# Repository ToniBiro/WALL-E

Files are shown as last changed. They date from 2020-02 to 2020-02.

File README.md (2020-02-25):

# WALL-E

We replicated the original Pixar friendly robot WALL-E.
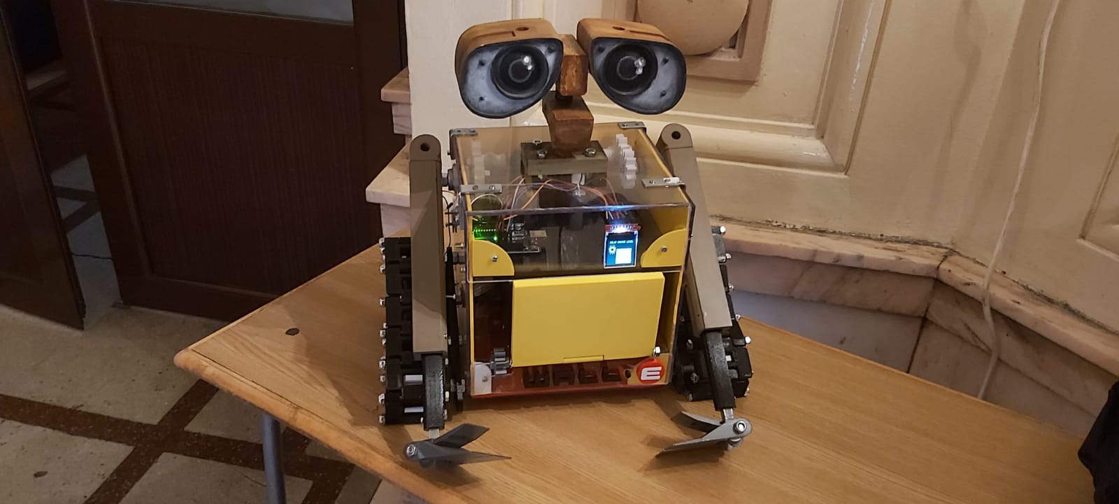
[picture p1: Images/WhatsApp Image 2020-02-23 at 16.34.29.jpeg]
our-wall-e


Wall-e is a robot that was left on earth to clean it up after the whole human race went off in space to live there while the earth was being cleaned up. He can move around, he can collect and compress the garbage and then pile it up in mountains (or solid and tidy structures).

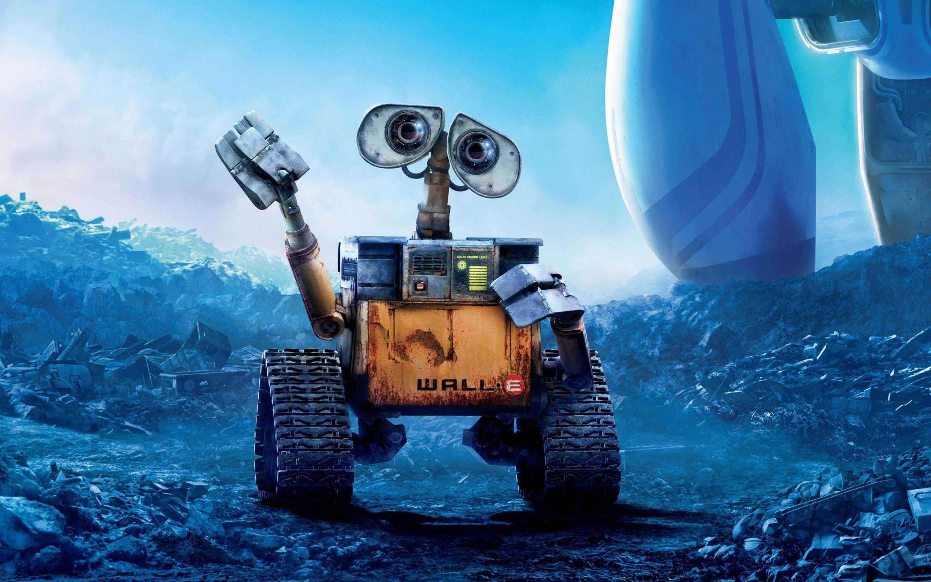
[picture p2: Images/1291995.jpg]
wall-e-original


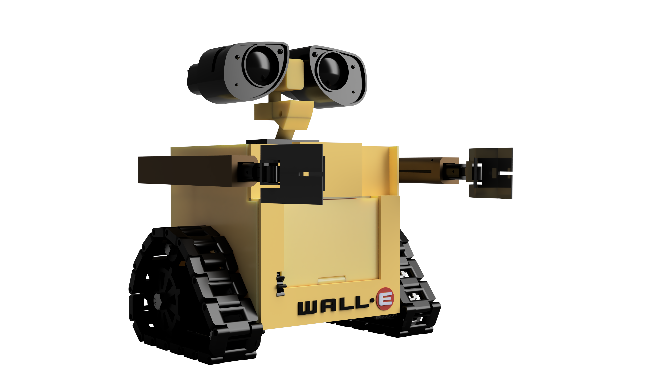
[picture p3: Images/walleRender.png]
  

### TEAM  
* [Antonia Biro-Balan](https://github.com/ToniBiro)
* [Mihai Stoian](https://github.com/mihainsto)

### Table of Contents
* [Features](#Features)
* [Usage](#Usage)
* [Video](#Video)
* [Roadmap](#Roadmap)
* [Materials and 3D models](#Materials)  

### Features
#### Overview
- Track/Wheel movement. He can move front and back but can't turn around yet.
- Arm movement. He can move them up and down but not front and back yet.
- Compression Room is existent but not completely assembeled yet.
- He is controlled via Bluetooth

#### Done
* Tracks movement  
the robot can move and rotate    
* Arm rotation  
the robot can move it's arms 180 deg  

#### To Do
* Hand slider movement  
* Compression chamber door movement  
* Assemble the compression process  

### Usage
The robot is controlled via a Bluetooth phone application.
While building him we used **Bluetooth RC Control** Android Mobile App.
We mapped all commands using this app but any other app can be used if we remap the command codes.

### Presentation Video  
[YouTube](https://youtu.be/xrvIICd3dlk)

## Roadmap
<table style="width:100%">

  <tr>
    <td>19 January</td>
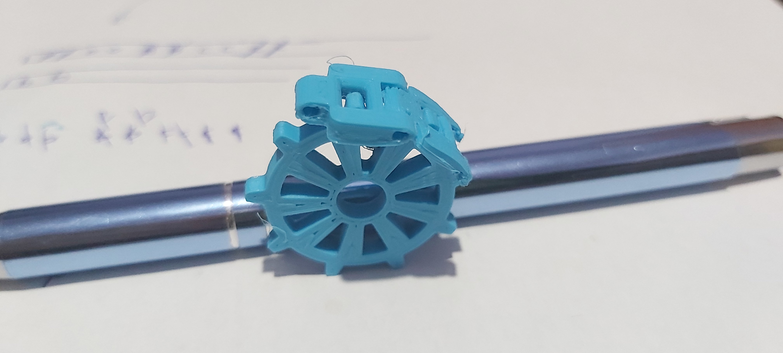
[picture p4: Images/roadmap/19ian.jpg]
    <td>
</td>
  </tr>
  <tr>
    <td>31 January</td>
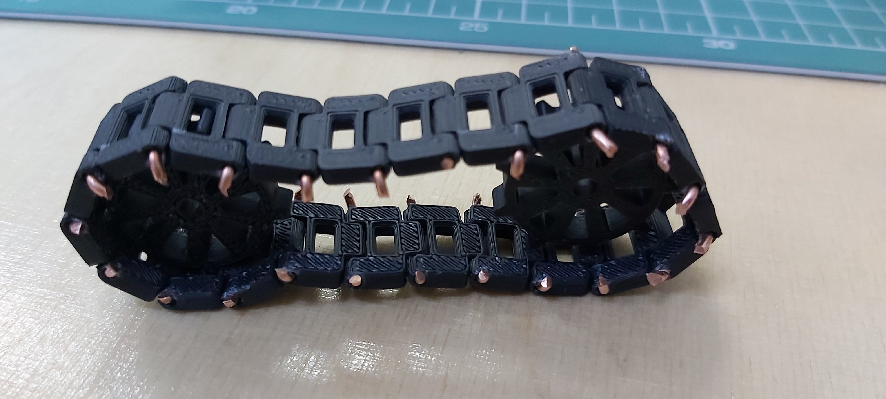
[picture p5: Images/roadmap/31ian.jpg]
    <td>
</td>
  </tr>
  <tr>
    <td>3 February</td>
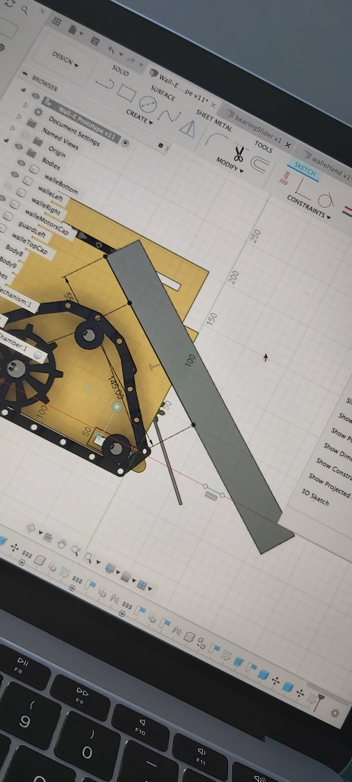
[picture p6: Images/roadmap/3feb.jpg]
    <td>
</td>
  </tr>
  <tr>
    <td>6 February</td>
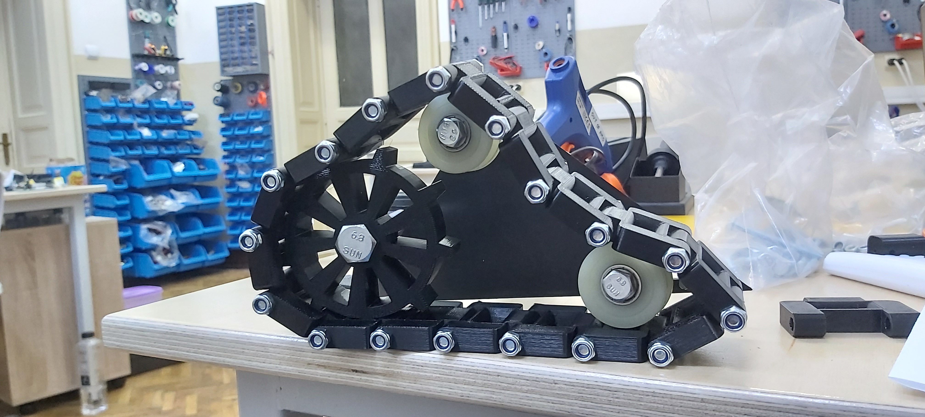
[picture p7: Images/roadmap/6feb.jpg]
    <td>
</td>
  </tr>
    <tr>
    <td>6 February</td>
    <td>
</td>
  </tr>
  <tr>
    <td>9 February</td>
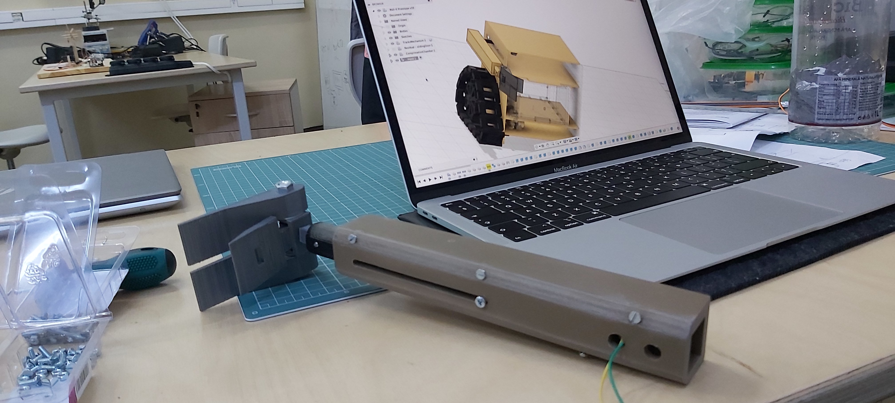
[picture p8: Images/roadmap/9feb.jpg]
    <td>
</td>
  </tr>
  <tr>
    <td>9 February</td>
    <td>
</td>
  </tr>
  <tr>
    <td>11 February</td>
    <td>
</td>
  </tr>
  <tr>
    <td>11 February</td>
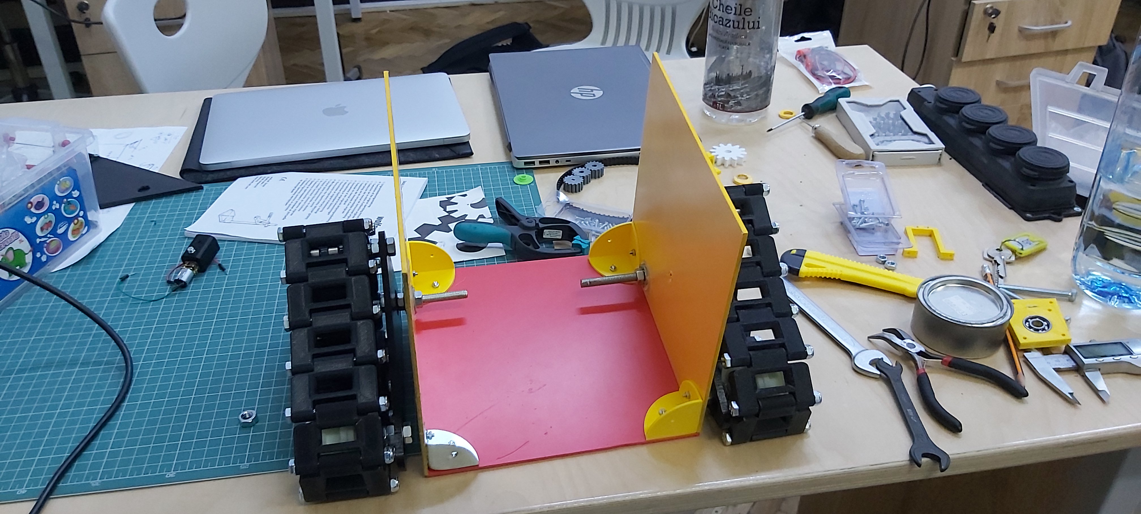
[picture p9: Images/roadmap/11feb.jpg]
    <td>
</td>
  </tr>
    <tr>
    <td>12 February</td>
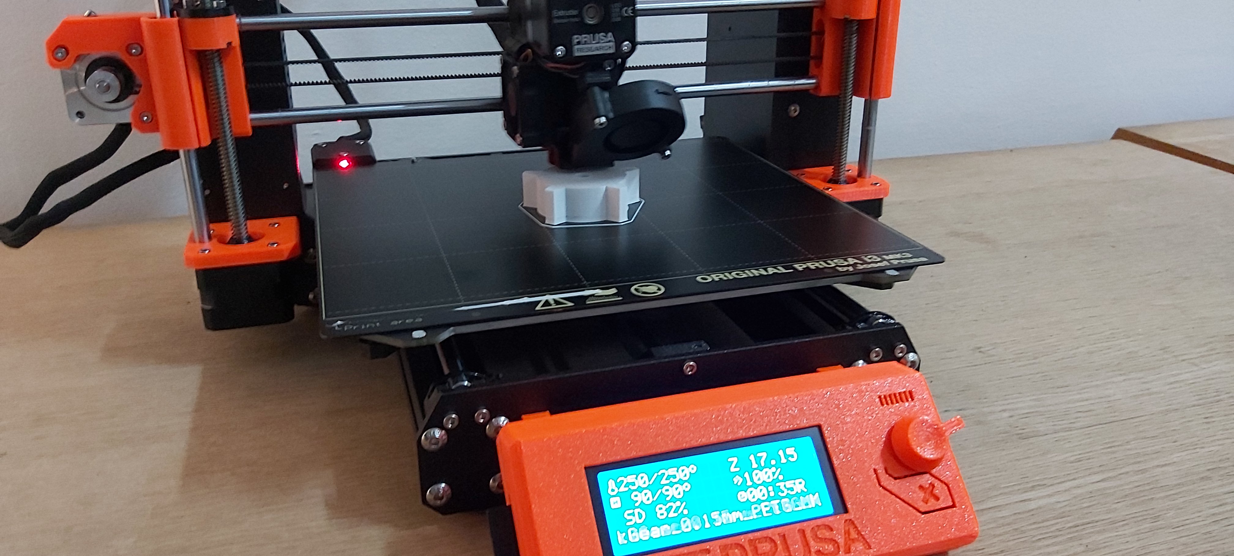
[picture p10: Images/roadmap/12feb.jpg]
    <td>
</td>
  </tr>
<tr>
    <td>15 February</td>
    <td>
</td>
  </tr>
  <tr>
    <td>20 February</td>
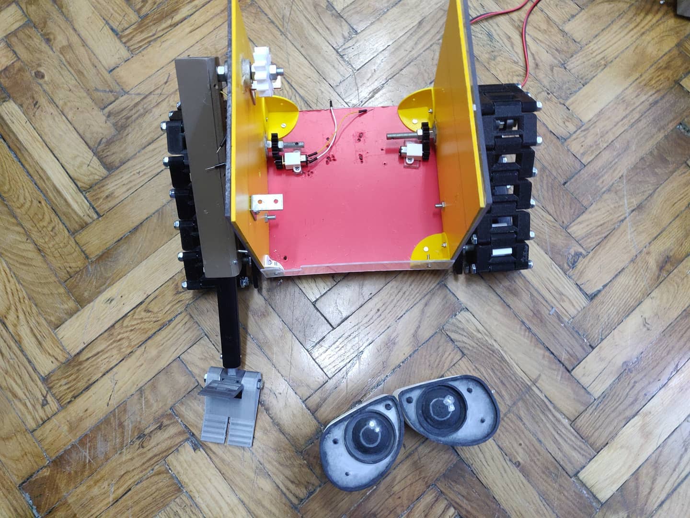
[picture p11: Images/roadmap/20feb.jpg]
    <td>
</td>
  </tr>
  </tr>
  <tr>
    <td>21 February</td>
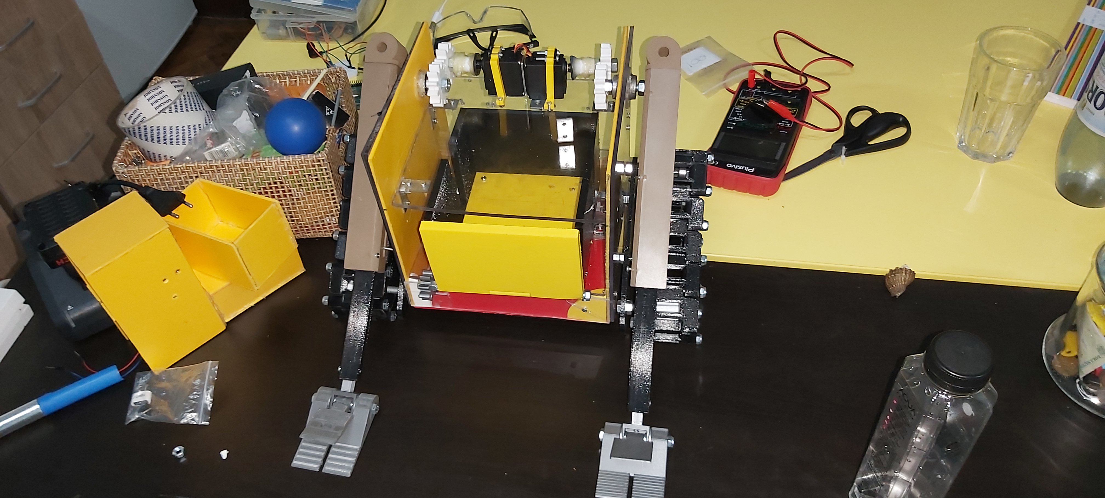
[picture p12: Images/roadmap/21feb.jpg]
    <td>
</td>
  </tr>
<tr>
    <td>22 February</td>
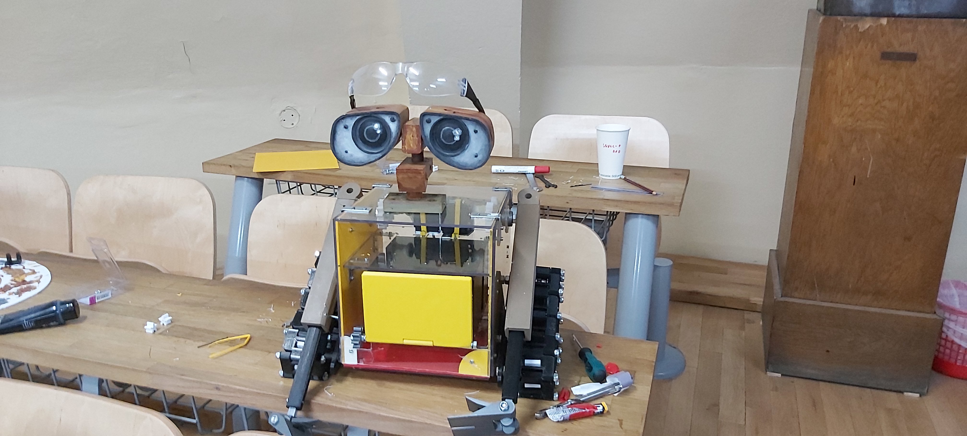
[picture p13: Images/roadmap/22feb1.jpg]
    <td>
</td>
  </tr>
  <tr>
    <td>22 February</td>
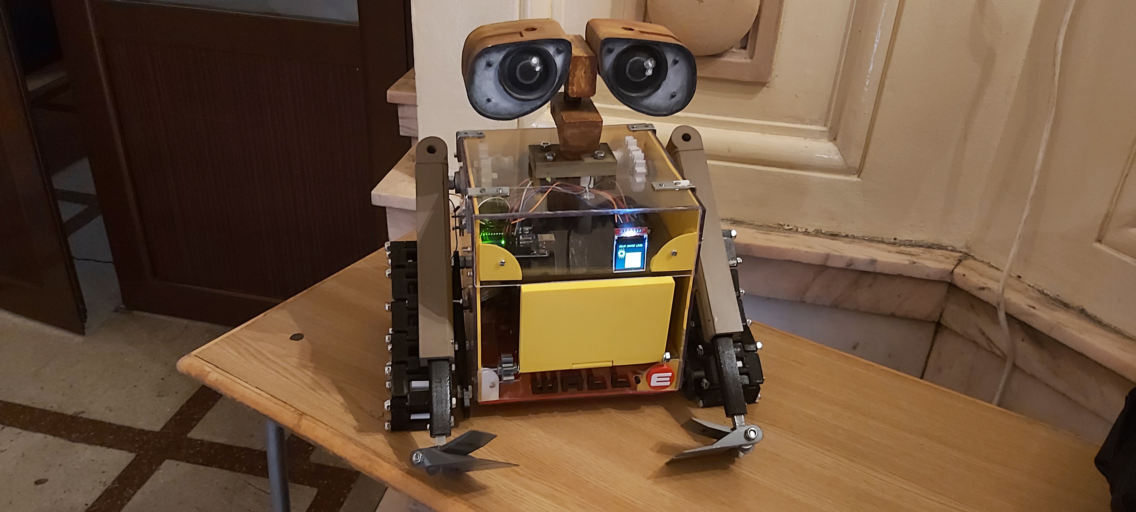
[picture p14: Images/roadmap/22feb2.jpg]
    <td>
</td>
  </tr>

</table>

### Materials and 3D models

#### Tracks
3D Printed - [files](/3D%20Parts/Tracks)
* 2x TractionGear
* 32x trackPiece
* 2x reinforcementTrackGuard
* 2x Gearbox Spur Gear (5 teeth)
* 2x Gearbox Spur Gear (10 teeth)
* 2x SmallTrackGear  

Other
* 2x 1000:1 DC Motors
* 8x 22 diameter bearings
* M8 M6 screws and nuts

#### Arm 
3D Printed - [files](/3D%20Parts/Arm)
* LeftArmleft
* LeftArmright
* LeftArmCoup
* LeftArmCilinder
* RightArmLeft
* RightArmright
* RightArmCoup
* RightArmCilinder
* 2x MotorCoupling
* 4x SpurGearArm
* 2x servoVerticalHolder
* 2x ArmMotorHolder  

Other
* 2x Servo motor
* 2x Dc motor
* M8 M3 bolts and nuts
* 4x 22 diameter bearings

#### Hand 
3D Printed - [files](/3D%20Parts/Hand)
* 2x ConnectionToCilinder
* 2x HandHolder
* 2x TwoFingers
* 2x ThirdFinger  

Other
* M4 M3 screws and nuts

#### Head 
3D Printed - [files](/3D%20Parts/Head)
* leftEye
* leftEyeMiddle
* leftEyeBack
* RightEye
* RightEyeMiddle
* RightEyeBack
* 45degreesCilinder
* bodyConnection
* connection
* connectionCilinder
* connectionCilinderSide  

Other
* M4 M12 bolts and nuts

#### Compression 
3D Printed - [files](/3D%20Parts/Compression)
* backWall
* compressor
* FloorWithHinge
* leftWall
* rightWall
* slidingDoor
* beltStepperSlider
* DoorVerticalStepperSlider
* Sliding Door Spur Gear (8 teeth)
* Sliding Door Spur Gear (16 teeth)
* slidingDoor
* 2x timingBeltGear
* timingBeltGearStepper  

Other
* M3 screws and nuts
* M6 bolts and nuts
* 2x 22 diameter bearings

#### Other 
3D Printed - [files](/3D%20Parts/Other)
* Wall-E text
* crate corners

## All Videos

- Track/Wheel Movement: https://drive.google.com/open?id=1swDcw1zlnlHRNl_Z5CJbrF9Ce5dbA-EY
- Arm movement: https://drive.google.com/open?id=1ivUnrZoqQpsUl6HV2EYKN_zgw3vp28cR

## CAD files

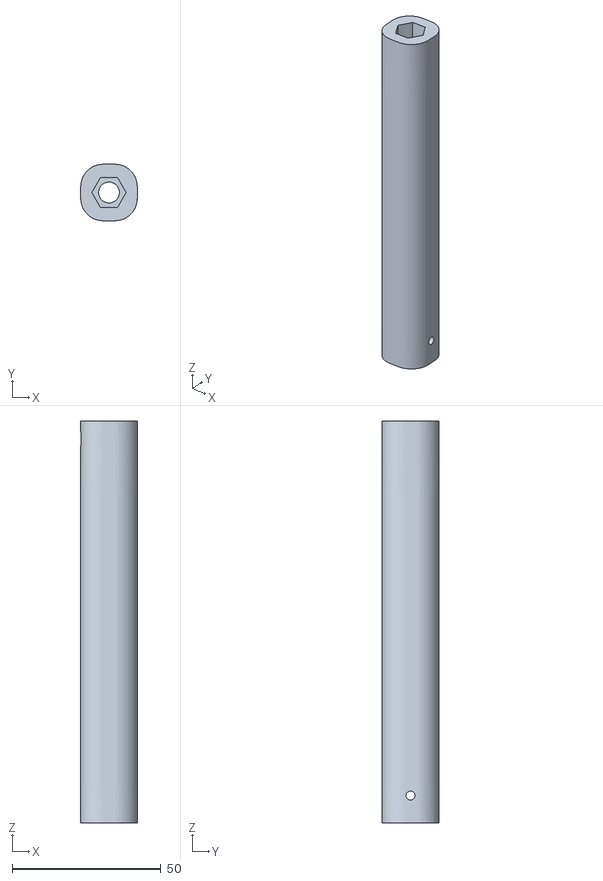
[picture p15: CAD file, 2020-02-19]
3D Parts/Arm/RightArmCilinder.stl
19.0 x 19.0 x 135.0

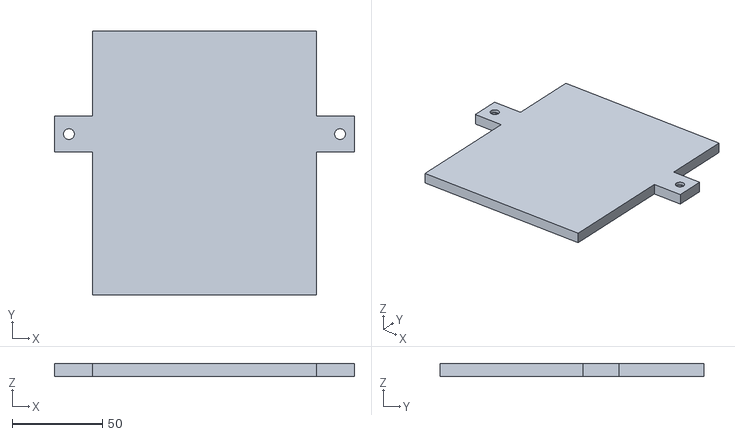
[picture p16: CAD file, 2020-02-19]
3D Parts/Compression/compressor.stl
166.0 x 146.0 x 7.00

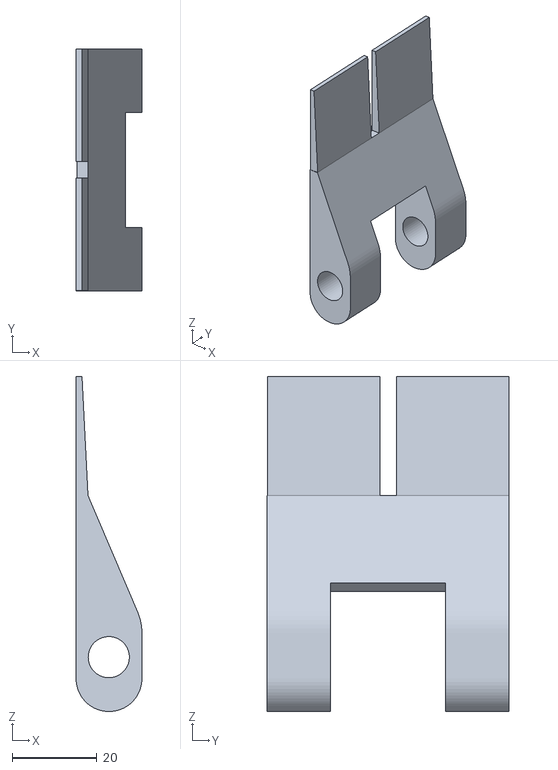
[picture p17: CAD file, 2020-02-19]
3D Parts/Hand/TwoFingers.stl
15.5 x 57.0 x 78.8

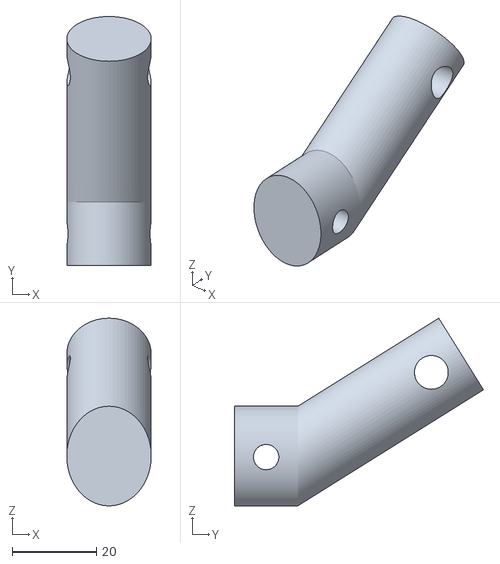
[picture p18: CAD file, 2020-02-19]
3D Parts/Head/45degreesCilinder.stl
20.0 x 59.0 x 44.4

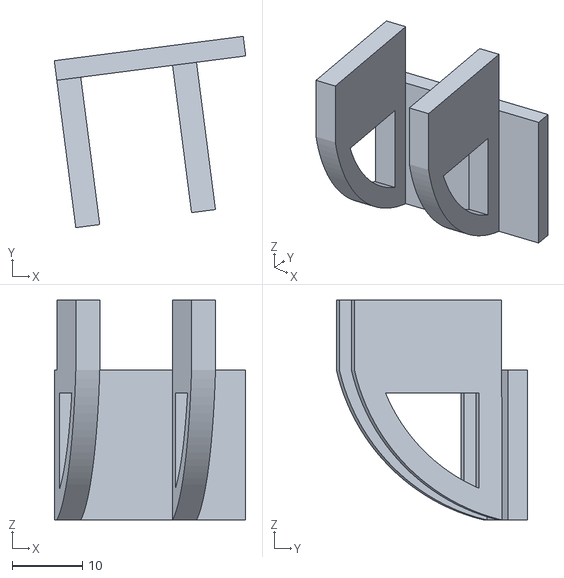
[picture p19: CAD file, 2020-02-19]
3D Parts/Head/LeftEye/leftEyeBack.stl
27.3 x 27.3 x 31.4

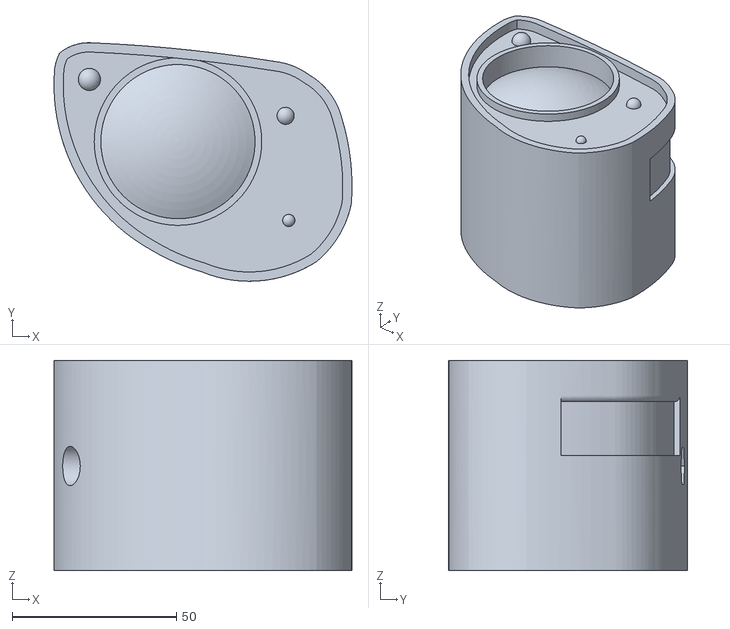
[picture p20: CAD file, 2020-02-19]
3D Parts/Head/RightEye/rightEye.stl
90.7 x 72.6 x 64.0

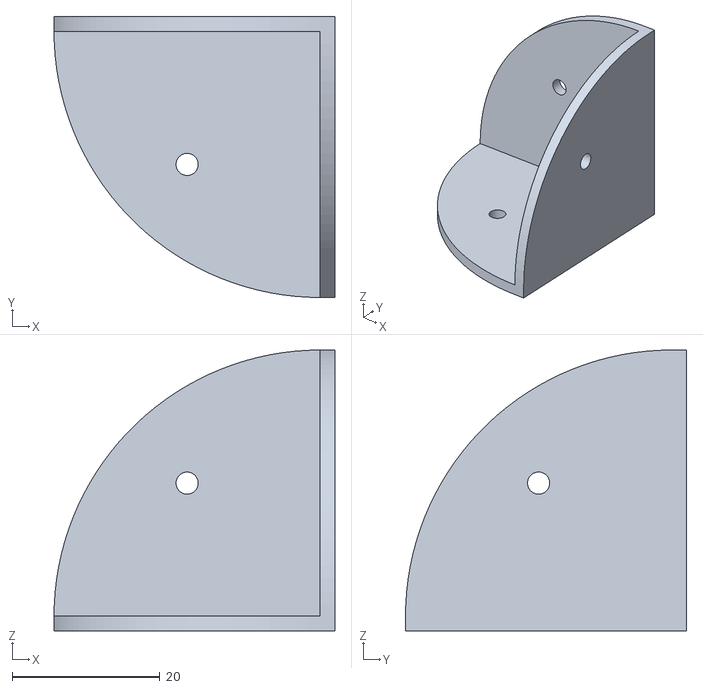
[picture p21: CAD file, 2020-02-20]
3D Parts/Other/crateCorner v1.stl
38.0 x 38.0 x 38.0

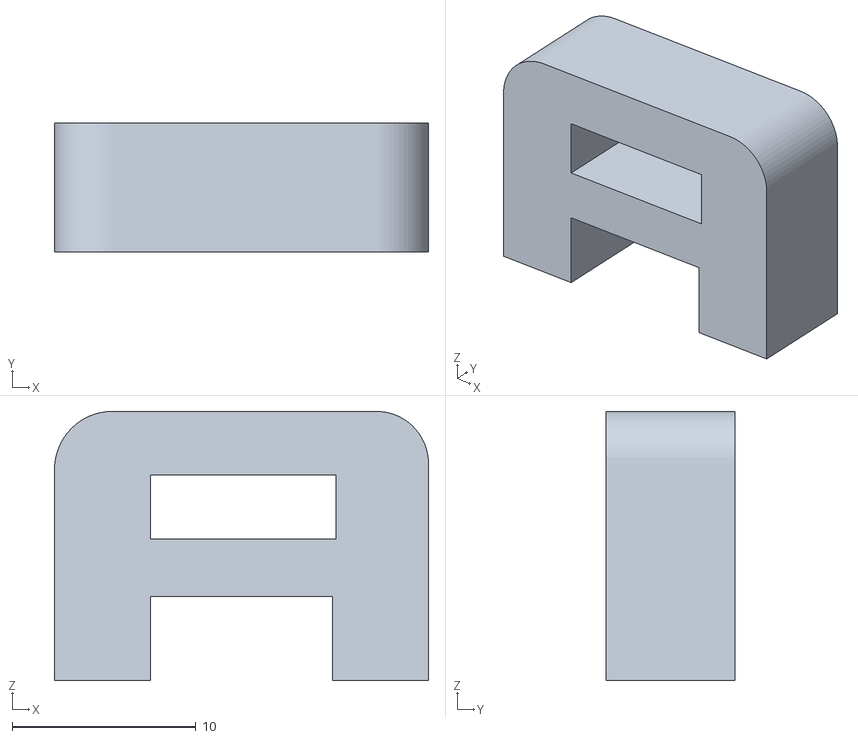
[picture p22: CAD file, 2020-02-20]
3D Parts/Other/Text/A.stl
20.3 x 7.00 x 14.6

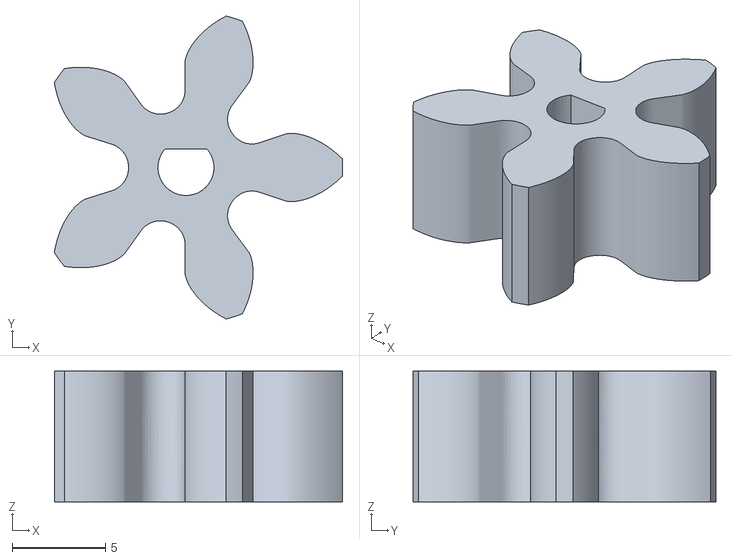
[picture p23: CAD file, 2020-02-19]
3D Parts/Tracks/Gearbox Spur Gear (5 teeth).stl
15.5 x 16.2 x 7.00

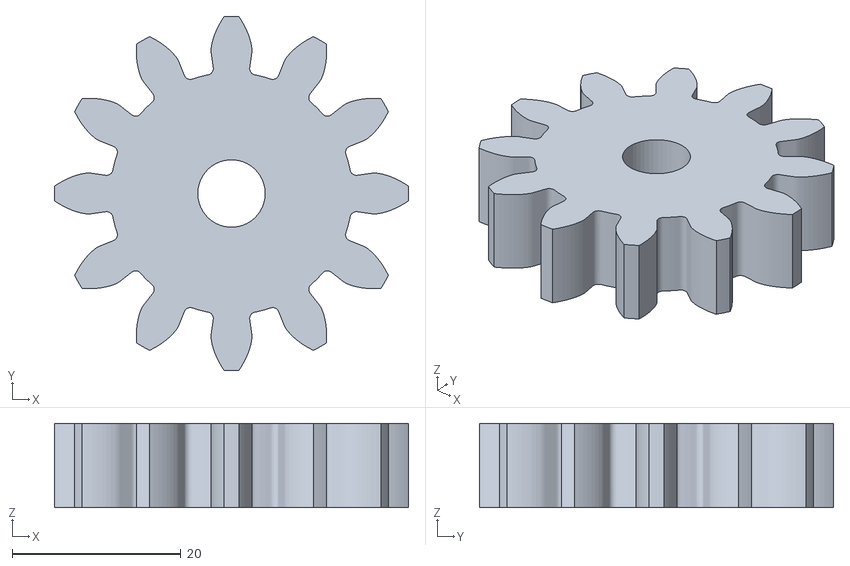
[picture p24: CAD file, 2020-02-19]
3D Parts/Arm/SpurGearArm.stl
42.0 x 42.0 x 10.0

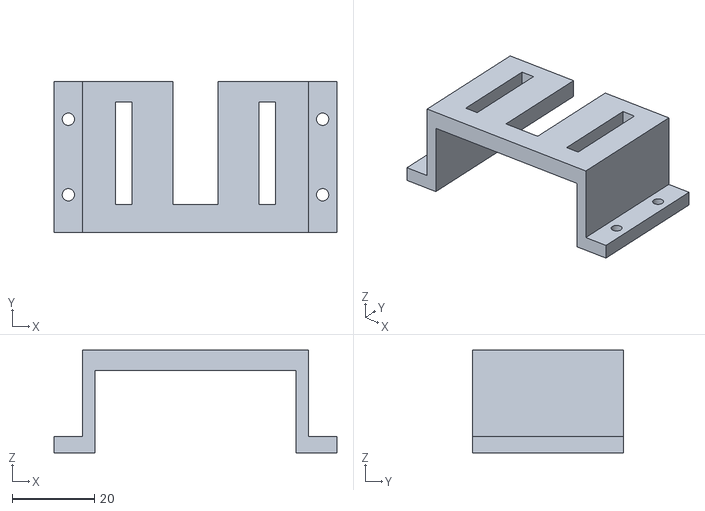
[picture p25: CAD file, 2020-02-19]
3D Parts/Compression/beltStepperSlider.stl
69.0 x 36.9 x 25.0

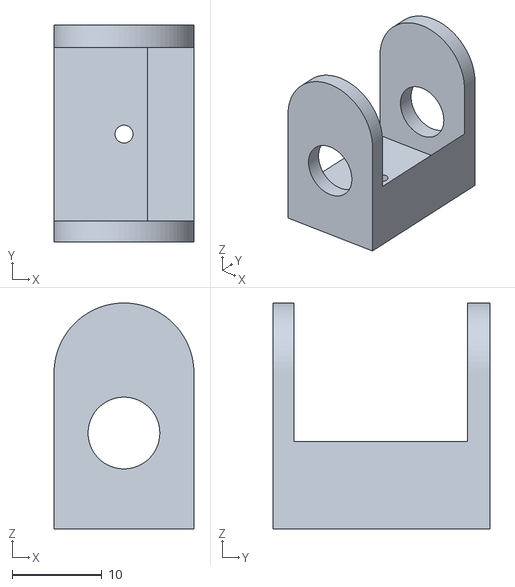
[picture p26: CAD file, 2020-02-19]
3D Parts/Hand/HandHolder.stl
15.6 x 24.2 x 25.2

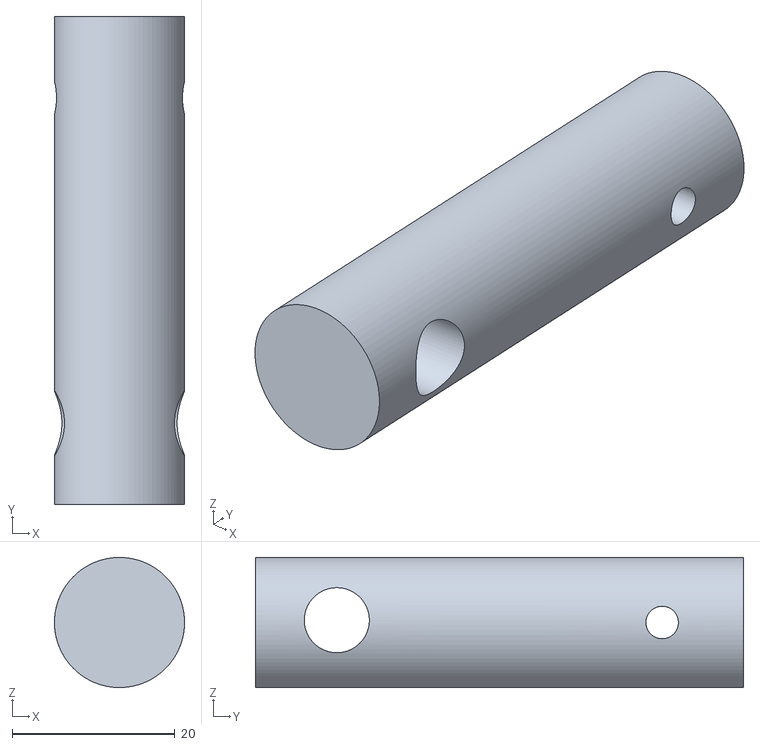
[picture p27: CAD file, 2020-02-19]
3D Parts/Head/connectionCilinder.stl
16.0 x 60.0 x 16.0

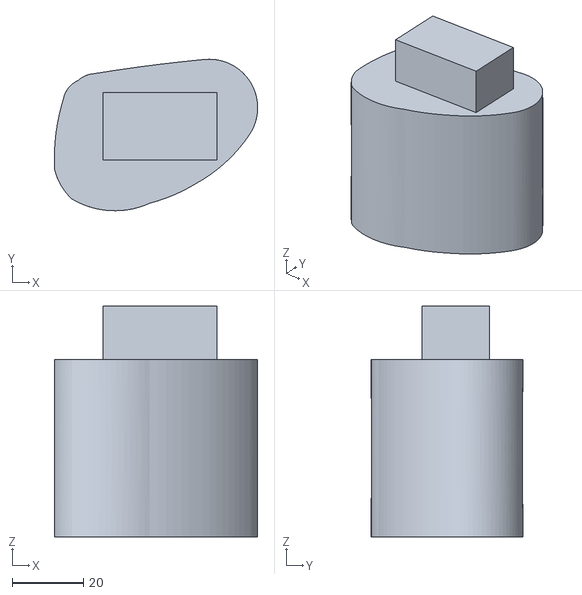
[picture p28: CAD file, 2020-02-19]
3D Parts/Head/LeftEye/leftEyeMiddle.stl
57.2 x 42.7 x 65.0

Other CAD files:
3D Parts/Head/RightEye/RightEyeBack.stl
3D Parts/Other/crateCornerSmall v2.stl
3D Parts/Other/Text/dot.stl
3D Parts/Tracks/TractionGear.stl
3D Parts/Arm/ArmMotorHolder.stl
3D Parts/Arm/LeftArm.f3d
3D Parts/Arm/LeftArmCilinder.stl
3D Parts/Arm/LeftArmCoup.stl
3D Parts/Arm/LeftArmleft.stl
3D Parts/Arm/LeftArmright.stl
3D Parts/Arm/MotorCoupling.stl
3D Parts/Arm/RightArm.f3d
3D Parts/Arm/RightArmCoup.stl
3D Parts/Arm/RightArmleft.stl
3D Parts/Arm/RightArmright.stl
3D Parts/Arm/armMotorHolder.f3d
3D Parts/Arm/servoVerticalHolder.f3d
3D Parts/Arm/servoVerticalHolder.stl
3D Parts/Compression/DoorVerticalStepperSlider.stl
3D Parts/Compression/FloorWithHinge.stl
3D Parts/Compression/Sliding Door Spur Gear (16 teeth).stl
3D Parts/Compression/Sliding Door Spur Gear (8 teeth).stl
3D Parts/Compression/backWall.stl
3D Parts/Compression/leftWall.stl
3D Parts/Compression/rightWall.stl
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

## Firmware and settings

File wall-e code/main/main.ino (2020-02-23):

#include "globalVariables.h"
#include "arm_movement.h"
#include "wave.h"
#include "wheel_movement.h"
#include "bluetooth.h"

void setup() {
  
  Serial.begin(9600); // communication with the bluetooth module
  SUART.begin(9600);
  pinMode(btPin0, INPUT);
  pinMode(btPin1, INPUT);
  rightArm.attach(10);
  leftArm.attach(9);
  rightArm.write(180);
  leftArm.write(5);
  
  motor1.setSpeed(220);
  motor4.setSpeed(220);
}

void loop() {

  // read the command from the bluetooth module
  read_commands();

  // when the "arms" variable is 0 it means that the control is taken by the wheels
  if(arms == 0){
    //control the wheels
    if (command == upArrow){
      move_forward(1);
      move_forward(2);
    }
  
    if (command == downArrow){
      move_backward(1);
      move_backward(2);
    }

    if(command == backLights || command == frontLights){
      stop_moving();
    }
    
  }
  // when the "arms" variable is 1 it means that the control is taken by the arms
  else{
    
    // first make sure the arm is not waving
    if(playOnceLeft == 1){
      // For the left arm we have the following mapping
      if(command == upArrow){
        move_left_arm_up(posServoLeftArm);
      }
      if(command == downArrow){
        move_left_arm_down(posServoLeftArm);
      }
    }

    if(playOnceRight == 1){
      // For the right arm we have the following mapping
      if(command == rightArrow){
        move_right_arm_up(posServoRightArm);
      }
      if(command == rightArrow){
        move_right_arm_down(posServoRightArm);
      }
    }

    // Make Wall-e wave
    //wave with left - aka 0
    if(command == frontLights && playOnceLeft == 0){
      wave(0);
      playOnceLeft = 1;
    }
    //wave with right - aka 1
    if(command == backLights && playOnceRight == 0){
      playOnceRight = 1;
      wave(1);
    }
  }

  // if the triangle button from the mobile app is pushed
  // the command swiches from the wheels to the arms and viceversa
  if(command == triangle){
    arms = !arms;
  }

  
}

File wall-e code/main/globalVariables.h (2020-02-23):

#pragma once

#include<SoftwareSerial.h>
#include <AFMotor.h>
#include <Servo.h>

// for the bluetooth module
SoftwareSerial SUART(A0, A1);

const int btPin0 = A0;
const int btPin1 = A1;

int command;

// the 2 servo motors that control the arms
Servo leftArm;
Servo rightArm;

// the position the servo motors are at all time
int posServoRightArm = 0;
int posServoLeftArm = 0;

// variable that is 0 if the wheels are in control or 1 if the arms are in control
boolean arms = 1;

// the 2 dc motors that control the wheels
AF_DCMotor motor1(1);
AF_DCMotor motor4(3);


// check to see if wall-e is waving or not
int playOnceLeft = 0;
int playOnceRight = 0;


// BUTTON READING FOR THE ANDROID APP USED
// the app we used is: 
// if different app is used just change the number of the command here
// default reading = 83

// right-arrow = 82
int rightArrow = 82;
// left-arrow = 76
int leftArrow = 76;
// up-arrow = 70
int upArrow = 70;
// down-arrow = 66
int downArrow = 66;
// up+left = 71
int upLeftArrow = 71;
// down+left = 72
int downLeftArrow = 72;
// up+right = 73
int upRightArrow = 73;
// down+right = 74
int downRightArrow = 74;
// front-lights = 119
int frontLights = 119;
// back-lights = 117
int backLights = 117;
// triangle = 120
int triangle = 120;

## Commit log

2020-02-19 added 3d parts and an incomplete version of readme
    [45degreesCilinder.stl, ArmMotorHolder.stl, ConnectionToCilinder.stl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]
2020-02-20 add arm movement control
2020-02-20 Added new 3D objects
    [A.stl, E.stl, L.stl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]
2020-02-23 add wheel control
2020-02-23 adjust arm movement
2020-02-24 moved text to other
    [A.stl, E.stl, L.stl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]
